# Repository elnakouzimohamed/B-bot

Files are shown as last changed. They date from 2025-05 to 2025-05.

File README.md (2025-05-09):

# 🤖 README – B-Bot Self-Balancing & Vision-Based Robot

## 📂 Project Structure

```
B-Bot/
│
├── computer_vision/
│   ├── vision.py
│   └── requirements.txt
│
├── fuzzyControlArduino/
│   ├── fuzzyControlArduino.ino
│   ├── MPU6050_tockn.cpp
│   ├── MPU6050_tockn.h
│   ├── testingMotots.ino
│   └── Trials/
│       ├── pid.ino
│       ├── thetaonly.ino
│       └── trial2.ino
│
├── matlab/
│   ├── b_bot.fis
│   └── Self_balancing_robot.slx
│
├── SOLIDWORKS/
│   ├── Robot Final (1).STL
│   └── Robot2.SLDPRT
│
└── README.md
```

## ⚙️ Main Functionalities Explained

| Component/Folder | Purpose and Functionality |
|---|---|
| `computer_vision/vision.py` | Raspberry Pi-based computer vision script that uses YOLOv8 to detect humans. If a human is detected, the image is compared to reference faces using SSIM. LEDs provide real-time feedback. |
| `fuzzyControlArduino.ino` | Arduino sketch implementing a fuzzy logic controller that keeps the robot balanced using tilt (theta) and angular velocity (dTheta) from the MPU6050 sensor. |
| `Trials/` | Experimental control codes: `pid.ino` for PID controller, `thetaonly.ino` for using only tilt angle, `trial2.ino` for hybrid attempts. |
| `testingMotots.ino` | Standalone motor testing script to check PWM behavior and motor direction. |
| `MPU6050_tockn.cpp/h` | Custom library for interfacing with the MPU6050 IMU module for tilt and angular velocity. |
| `matlab/b_bot.fis` | MATLAB Fuzzy Inference System (FIS) file with the same logic used in Arduino; useful for visual tuning and simulations. |
| `matlab/Self_balancing_robot.slx` | Full Simulink simulation model with multibody setup to test the control system virtually. |
| `SOLIDWORKS/Robot Final (1).STL` | Exported 3D printable chassis design for fabrication. |
| `SOLIDWORKS/Robot2.SLDPRT` | Source CAD file for modifying robot design in SolidWorks. |

---

## 🛠️ Requirements

### For Raspberry Pi:
Install the required packages:
```bash
cd computer_vision
pip install -r requirements.txt
```

Key packages:
- `ultralytics` (YOLOv8)
- `opencv-python`
- `picamera2`
- `scikit-image`
- `RPi.GPIO`

System-level dependencies:
```bash
sudo apt install -y python3-picamera2 python3-rpi.gpio
```

---

## 🚀 How to Run

### Computer Vision (on Raspberry Pi):
```bash
cd computer_vision
python3 vision.py
```

### Arduino:
- Open `fuzzyControlArduino.ino` or any file from `Trials/` in Arduino IDE
- Select your board and COM port
- Upload to your Arduino

### MATLAB/Simulink:
- Open `b_bot.fis` in the Fuzzy Logic Designer
- Simulate `Self_balancing_robot.slx` to validate or tune the logic

---

## 🎥 Demo Video

Watch the Full Video Demo (https://www.youtube.com/watch?v=OxzO8reckg4)

---

> Created by **Mohamed El Nakouzi, Rached El Bitar, and Daniel Nassar** — combining fuzzy logic, computer vision, and mechanical design in a mechatronic system.

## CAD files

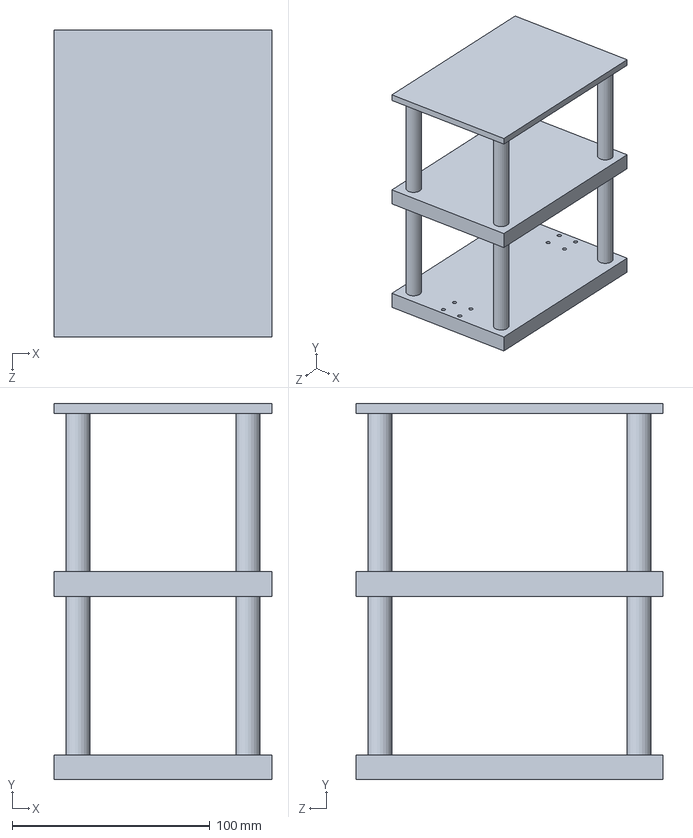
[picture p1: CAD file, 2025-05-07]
SOLIDWORKS/Robot2.SLDPRT
110.0 x 190.0 x 155.0 mm

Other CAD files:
SOLIDWORKS/Robot Final (1).STL

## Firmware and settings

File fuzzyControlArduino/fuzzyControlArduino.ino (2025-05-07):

#include <Wire.h>
#include <math.h>
#include "MPU6050_tockn.h"
#include <Fuzzy.h>

// Fuzzy Input Scaling
float theta_input_scale = 1.0;
float theta_input_bias = 0.0;

float dtheta_input_scale = 0.75;
float dtheta_input_bias = 0.0;

// Fuzzy Output Scaling
float output_mf_scale = 1.0;
float output_mf_bias = 0.0;

// Motor driver pins
#define LEFT_IN1 8
#define LEFT_IN2 7
#define LEFT_EN  9
#define RIGHT_IN2 11
#define RIGHT_IN1 10
#define RIGHT_EN 9  // Same as LEFT_EN

// Constants
const int DELTA_T = 5; // ms

// Global variables
MPU6050 mpu6050(Wire);
unsigned long current_time = 0;
unsigned long previous_time = 0;

// Complementary filter
float alpha = 0.96;
float filteredAngle = 0.0;
float filteredDTheta = 0.0;

// Fuzzy logic components
Fuzzy* fuzzy = new Fuzzy();
FuzzyInput* theta = new FuzzyInput(1);
FuzzyInput* dtheta = new FuzzyInput(2);
FuzzyOutput* balance = new FuzzyOutput(1);

// Motor Controller Class (Direction Only)
class MotorController {
  private:
    int in1Pin;
    int in2Pin;

  public:
    MotorController(int in1, int in2) {
      in1Pin = in1;
      in2Pin = in2;
      pinMode(in1Pin, OUTPUT);
      pinMode(in2Pin, OUTPUT);
    }

    void setDirection(int pwm) {
      if (pwm > 0) {
        digitalWrite(in1Pin, LOW);
        digitalWrite(in2Pin, HIGH);
      } else if (pwm < 0) {
        digitalWrite(in1Pin, HIGH);
        digitalWrite(in2Pin, LOW);
      } else {
        digitalWrite(in1Pin, LOW);
        digitalWrite(in2Pin, LOW);
      }
    }
};

// Motors (no need for EN in the controller)
MotorController leftMotor(LEFT_IN1, LEFT_IN2);
MotorController rightMotor(RIGHT_IN1, RIGHT_IN2);

void setup() {
  Serial.begin(115200);
  Serial.println("Self-Balancing Robot Starting...");

  Wire.begin();
  mpu6050.begin();
  Serial.println("MPU6050 Initialized.");

  delay(100);
  Serial.println("Please keep the robot still for gyro calibration...");
  delay(5000);
  mpu6050.calcGyroOffsets(true);
  Serial.println("Gyroscope Calibration Completed.");

  setupFuzzyLogic();
  pinMode(LEFT_EN, OUTPUT);  // PWM shared
  Serial.println("Setup Completed.");
}

void loop() {
  current_time = millis();
  mpu6050.update();

  if ((current_time - previous_time) > DELTA_T) {
    float dt = (current_time - previous_time) / 1000.0;

    float accAngle = mpu6050.getAccAngleX();
    float gyroRate = mpu6050.getGyroX();

    filteredAngle = alpha * (filteredAngle + gyroRate * dt) + (1 - alpha) * accAngle;

    // Smoothed dTheta
    filteredDTheta = 0.9 * filteredDTheta + 0.1 * gyroRate;

    if (isnan(filteredAngle) || isnan(filteredDTheta)) {
      Serial.println("Sensor error! Stopping motors.");
      analogWrite(LEFT_EN, 0);
      return;
    }

    float balance_voltage = computeBalanceVoltage(filteredAngle, filteredDTheta);
    balance_voltage = constrain(balance_voltage, -2.5, 2.5);

    float pwm_command = (balance_voltage * 255.0) / 3.0;
    pwm_command = constrain(pwm_command, -255.0, 255.0);

    // Dead zone
    if (abs(pwm_command) < 20) pwm_command = 0;

    leftMotor.setDirection((int)pwm_command);
    rightMotor.setDirection((int)pwm_command);

    analogWrite(LEFT_EN, min(abs((int)(pwm_command * 2.25)), 255));

    Serial.println("========== Robot State ==========");
    Serial.print("Theta Error (filtered): "); Serial.print(filteredAngle); Serial.println(" deg");
    Serial.print("dTheta (filtered): "); Serial.print(filteredDTheta); Serial.println(" deg/s");
    Serial.print("Fuzzy Output (Voltage): "); Serial.println(balance_voltage);
    Serial.print("PWM Command: "); Serial.println(pwm_command);
    Serial.println("==================================");

    previous_time = current_time;
  }
}

void setupFuzzyLogic() {
  // Theta input sets
  FuzzySet* theta_neg = new FuzzySet(
    theta_input_scale * (-45 + theta_input_bias),
    theta_input_scale * (-20 + theta_input_bias),
    theta_input_scale * (-20 + theta_input_bias),
    theta_input_scale * (-5  + theta_input_bias));

  FuzzySet* theta_bal = new FuzzySet(
    theta_input_scale * (-10 + theta_input_bias),
    theta_input_scale * (  0 + theta_input_bias),
    theta_input_scale * (  0 + theta_input_bias),
    theta_input_scale * ( 10 + theta_input_bias));

  FuzzySet* theta_pos = new FuzzySet(
    theta_input_scale * (  5 + theta_input_bias),
    theta_input_scale * ( 20 + theta_input_bias),
    theta_input_scale * ( 20 + theta_input_bias),
    theta_input_scale * ( 45 + theta_input_bias));

  theta->addFuzzySet(theta_neg);
  theta->addFuzzySet(theta_bal);
  theta->addFuzzySet(theta_pos);
  fuzzy->addFuzzyInput(theta);

  // dTheta input sets
  FuzzySet* dtheta_neg = new FuzzySet(
    dtheta_input_scale * (-45 + dtheta_input_bias),
    dtheta_input_scale * (-15 + dtheta_input_bias),
    dtheta_input_scale * (-15 + dtheta_input_bias),
    dtheta_input_scale * ( -5 + dtheta_input_bias));

  FuzzySet* dtheta_zero = new FuzzySet(
    dtheta_input_scale * (-5 + dtheta_input_bias),
    dtheta_input_scale * (   0 + dtheta_input_bias),
    dtheta_input_scale * (   0 + dtheta_input_bias),
    dtheta_input_scale * ( 5 + dtheta_input_bias));

  FuzzySet* dtheta_pos = new FuzzySet(
    dtheta_input_scale * (  5 + dtheta_input_bias),
    dtheta_input_scale * ( 15 + dtheta_input_bias),
    dtheta_input_scale * ( 15 + dtheta_input_bias),
    dtheta_input_scale * ( 45 + dtheta_input_bias));

  dtheta->addFuzzySet(dtheta_neg);
  dtheta->addFuzzySet(dtheta_zero);
  dtheta->addFuzzySet(dtheta_pos);
  fuzzy->addFuzzyInput(dtheta);

  // Balance output sets
  FuzzySet* out_high_neg = new FuzzySet(
    output_mf_scale * (-5.0 + output_mf_bias),
    output_mf_scale * (-3.0 + output_mf_bias),
    output_mf_scale * (-2.0 + output_mf_bias),
    output_mf_scale * (-1.0 + output_mf_bias));

  FuzzySet* out_low_neg = new FuzzySet(
    output_mf_scale * (-2.0 + output_mf_bias),
    output_mf_scale * (-1.0 + output_mf_bias),
    output_mf_scale * (-0.5 + output_mf_bias),
    output_mf_scale * ( 0.0 + output_mf_bias));

  FuzzySet* out_average = new FuzzySet(
    output_mf_scale * (-0.25 + output_mf_bias),
    output_mf_scale * ( 0.0   + output_mf_bias),
    output_mf_scale * ( 0.0   + output_mf_bias),
    output_mf_scale * ( 0.25  + output_mf_bias));

  FuzzySet* out_low_pos = new FuzzySet(
    output_mf_scale * ( 0.0 + output_mf_bias),
    output_mf_scale * ( 0.5 + output_mf_bias),
    output_mf_scale * ( 1.0 + output_mf_bias),
    output_mf_scale * ( 2.0 + output_mf_bias));

  FuzzySet* out_high_pos = new FuzzySet(
    output_mf_scale * ( 1.0 + output_mf_bias),
    output_mf_scale * ( 2.0 + output_mf_bias),
    output_mf_scale * ( 3.0 + output_mf_bias),
    output_mf_scale * ( 5.0 + output_mf_bias));

  balance->addFuzzySet(out_high_neg);
  balance->addFuzzySet(out_low_neg);
  balance->addFuzzySet(out_average);
  balance->addFuzzySet(out_low_pos);
  balance->addFuzzySet(out_high_pos);
  fuzzy->addFuzzyOutput(balance);

  // Fuzzy rules
  FuzzyRuleAntecedent* r1 = new FuzzyRuleAntecedent();
  r1->joinWithAND(theta_pos, dtheta_pos);
  FuzzyRuleConsequent* c1 = new FuzzyRuleConsequent();
  c1->addOutput(out_high_pos);
  fuzzy->addFuzzyRule(new FuzzyRule(1, r1, c1));

  FuzzyRuleAntecedent* r2 = new FuzzyRuleAntecedent();
  r2->joinWithAND(theta_pos, dtheta_neg);
  FuzzyRuleConsequent* c2 = new FuzzyRuleConsequent();
  c2->addOutput(out_low_neg);
  fuzzy->addFuzzyRule(new FuzzyRule(2, r2, c2));

  FuzzyRuleAntecedent* r3 = new FuzzyRuleAntecedent();
  r3->joinWithAND(theta_neg, dtheta_neg);
  FuzzyRuleConsequent* c3 = new FuzzyRuleConsequent();
  c3->addOutput(out_high_neg);
  fuzzy->addFuzzyRule(new FuzzyRule(3, r3, c3));

  FuzzyRuleAntecedent* r4 = new FuzzyRuleAntecedent();
  r4->joinWithAND(theta_neg, dtheta_pos);
  FuzzyRuleConsequent* c4 = new FuzzyRuleConsequent();
  c4->addOutput(out_low_pos);
  fuzzy->addFuzzyRule(new FuzzyRule(4, r4, c4));

  FuzzyRuleAntecedent* r5 = new FuzzyRuleAntecedent();
  r5->joinWithAND(theta_bal, dtheta_neg);
  FuzzyRuleConsequent* c5 = new FuzzyRuleConsequent();
  c5->addOutput(out_low_neg);
  fuzzy->addFuzzyRule(new FuzzyRule(5, r5, c5));

  FuzzyRuleAntecedent* r6 = new FuzzyRuleAntecedent();
  r6->joinWithAND(theta_bal, dtheta_pos);
  FuzzyRuleConsequent* c6 = new FuzzyRuleConsequent();
  c6->addOutput(out_low_pos);
  fuzzy->addFuzzyRule(new FuzzyRule(6, r6, c6));
}

float computeBalanceVoltage(float theta_val, float dtheta_val) {
  fuzzy->setInput(1, theta_val);
  fuzzy->setInput(2, dtheta_val);
  fuzzy->fuzzify();
  return fuzzy->defuzzify(1);
}

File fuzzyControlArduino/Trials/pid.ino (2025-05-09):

#include <Wire.h>
#include <math.h>
#include "MPU6050_tockn.h"

// Motor driver pins
#define LEFT_IN1 9
#define LEFT_IN2 8
#define LEFT_EN  10

#define RIGHT_IN1 11
#define RIGHT_IN2 12
#define RIGHT_EN 5

// Encoder pins (optional)
#define leftmotor_A 2
#define leftmotor_B 4

// Constants
const float SETPOINT = 0.0;     // Target angle (upright)
const int DELTA_T = 10;         // Loop time in ms
const float MAX_PWM = 255.0;    // Max motor signal

// PID Gains (adjust based on behavior)
float Kp = 15.0;
float Ki = 0.3;
float Kd = 2.0;

// Variables
MPU6050 mpu(Wire);
volatile int left_count = 0;
float error_sum = 0;
float last_error = 0;
unsigned long last_time = 0;

// ========== Motor Control Class ==========
class MotorController {
  private:
    int in1, in2, en;
  public:
    MotorController(int a, int b, int e) : in1(a), in2(b), en(e) {
      pinMode(in1, OUTPUT);
      pinMode(in2, OUTPUT);
      pinMode(en, OUTPUT);
    }

    void setPWM(float pwm) {
      pwm = -pwm;  // flip if needed — test your setup!
      pwm = constrain(pwm, -MAX_PWM, MAX_PWM);

      if (pwm > 0) {
        digitalWrite(in1, LOW);
        digitalWrite(in2, HIGH);
      } else if (pwm < 0) {
        digitalWrite(in1, HIGH);
        digitalWrite(in2, LOW);
      } else {
        digitalWrite(in1, LOW);
        digitalWrite(in2, LOW);
      }

      analogWrite(en, constrain(abs((int)pwm), 0, 255));
    }
};

MotorController leftMotor(LEFT_IN1, LEFT_IN2, LEFT_EN);
MotorController rightMotor(RIGHT_IN1, RIGHT_IN2, RIGHT_EN);

// ========== Setup ==========
void setup() {
  Serial.begin(115200);
  Wire.begin();
  mpu.begin();

  delay(500);
  Serial.println("Calibrating MPU6050...");
  delay(3000);
  mpu.calcGyroOffsets(true);
  Serial.println("Calibration complete.");

  pinMode(leftmotor_A, INPUT);
  pinMode(leftmotor_B, INPUT);
  attachInterrupt(digitalPinToInterrupt(leftmotor_A), phase_A_left, RISING);

  last_time = millis();
}

// ========== Main Loop ==========
void loop() {
  unsigned long now = millis();
  if (now - last_time >= DELTA_T) {
    mpu.update();

    float angle = mpu.getAngleX();
    float gyro = mpu.getGyroX();

    float error = SETPOINT - angle;
    error_sum += error * DELTA_T;
    error_sum = constrain(error_sum, -1000, 1000);  // Prevent wind-up

    float d_error = (error - last_error) / DELTA_T;
    last_error = error;

    float P = Kp * error;
    float I = Ki * error_sum;
    float D = Kd * d_error;
    float output = P + I + D;
    output = constrain(output, -MAX_PWM, MAX_PWM);

    leftMotor.setPWM(output);
    rightMotor.setPWM(output);

    // ======= Serial Logging =======
    Serial.print("Angle: "); Serial.print(angle, 2);
    Serial.print(" | P: "); Serial.print(P, 2);
    Serial.print(" | I: "); Serial.print(I, 2);
    Serial.print(" | D: "); Serial.print(D, 2);
    Serial.print(" | OUT: "); Serial.println(output, 2);

    last_time = now;
  }
}

// ========== Encoder Interrupt ==========
void phase_A_left() {
  if (digitalRead(leftmotor_A)) {
    left_count += digitalRead(leftmotor_B) ? -1 : 1;
  } else {
    left_count += digitalRead(leftmotor_B) ? 1 : -1;
  }
}
